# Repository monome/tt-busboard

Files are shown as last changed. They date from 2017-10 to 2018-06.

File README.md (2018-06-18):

# teletype busboard

provides 12 ii headers and additional pull-up to support larger ii networks.

## bom

see http://digikey.com

* (1) header, female, 2x3 [S7071-ND](https://www.digikey.com/products/en?keywords=S7071-ND)
* (12) header, male, 2x3 [609-3218-ND](https://www.digikey.com/products/en?keywords=609-3218-ND)
* (1) 3v3 reg [AZ1117CH-3.3TRG1DICT-ND](https://www.digikey.com/products/en?keywords=Z1117CH-3.3TRG1DICT-ND)
* (1) header, female, 2x5 [S6105-ND](https://www.digikey.com/products/en?keywords=S6105-ND)
* (2) resistor 1206 2.2k [P2.20KFCT-ND](https://www.digikey.com/products/en?keywords=P2.20KFCT-ND)
* (1) header, male, shrouded, 2x5 [ED1543-ND](https://www.digikey.com/products/en?keywords=ED1543-ND)

pcb via oshpark: https://oshpark.com/shared_projects/kg4mZSCg 

## guide

* full kit contents:

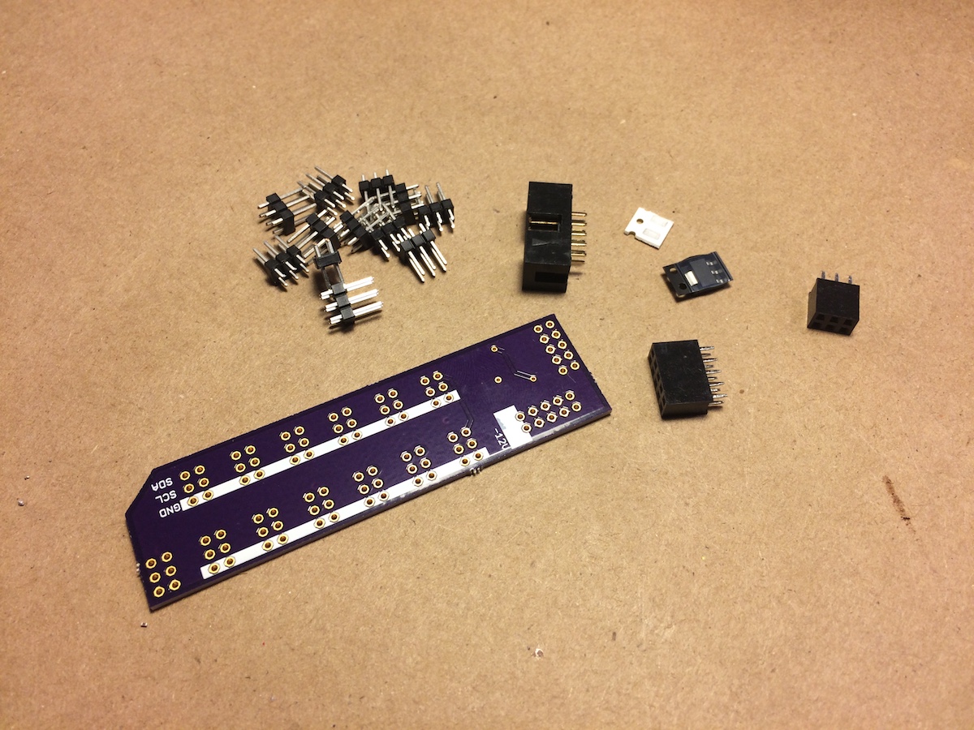
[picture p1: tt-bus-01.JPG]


* solder the SMD pads first, one for each part. use tweezers to place the part while heating the soldered pad with the iron. pull the iron away while holding the part, let the solder cool.

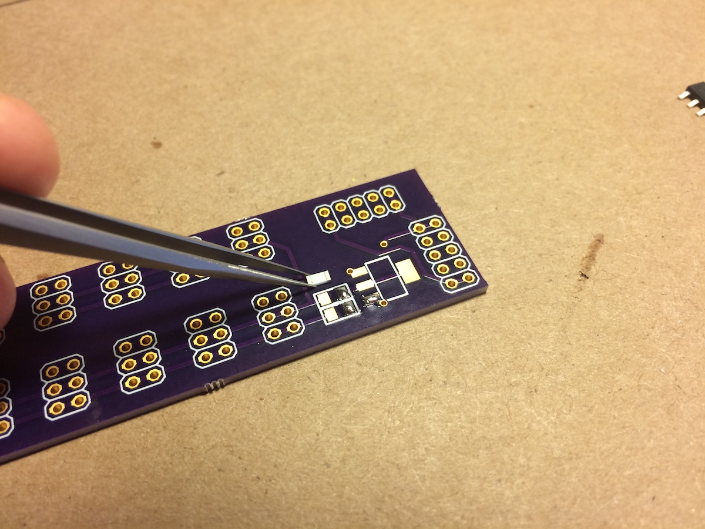
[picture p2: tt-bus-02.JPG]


* then solder the other remaining legs of the parts:

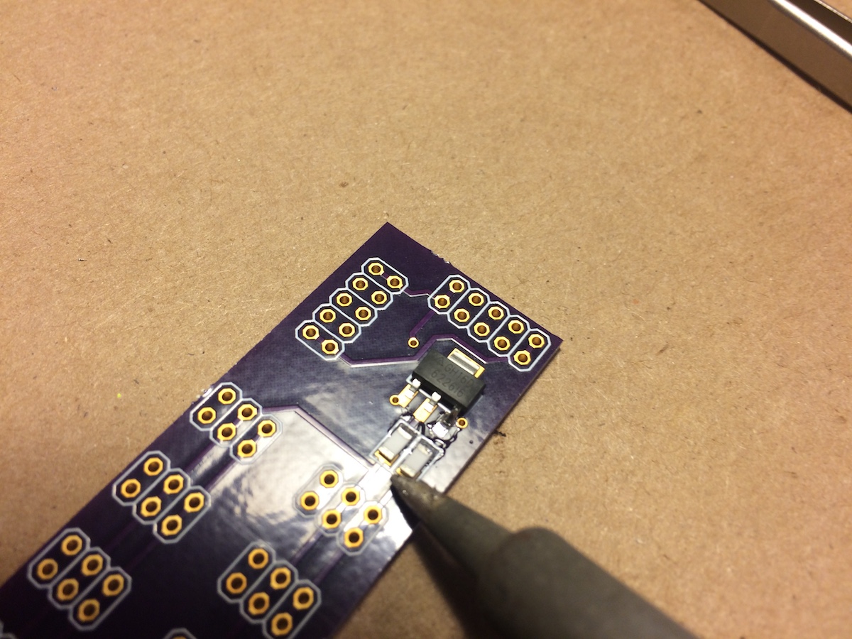
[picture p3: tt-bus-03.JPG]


* should look more or less like this:

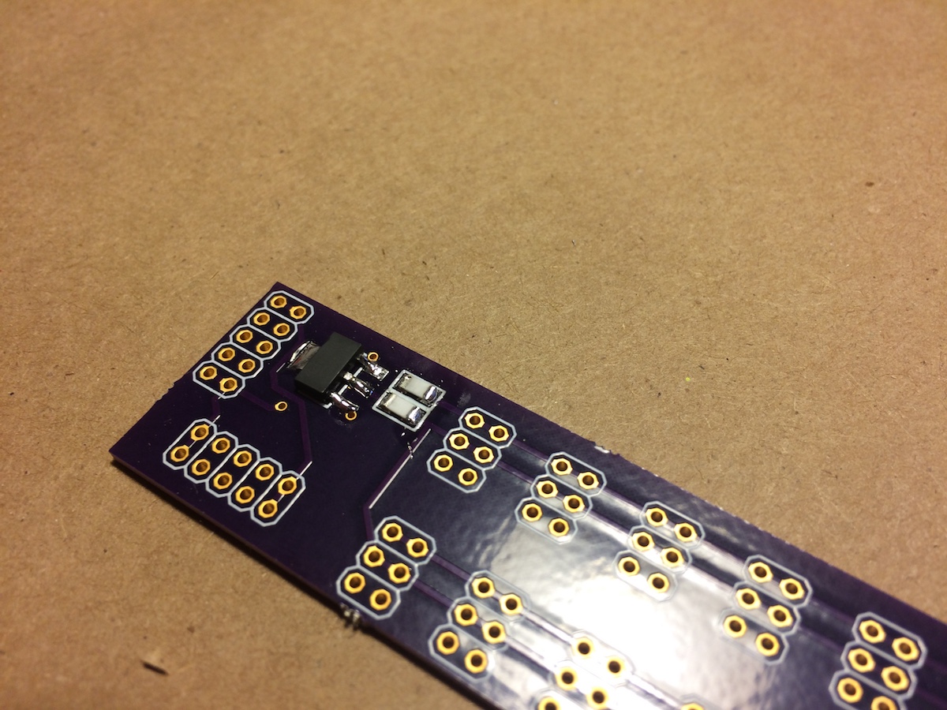
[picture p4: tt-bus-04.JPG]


* insert the 12 headers as shown and then solder the other side. may require a trick to flip it without having them fall out-- try a bit of cardboard to hold it all together while flipping:

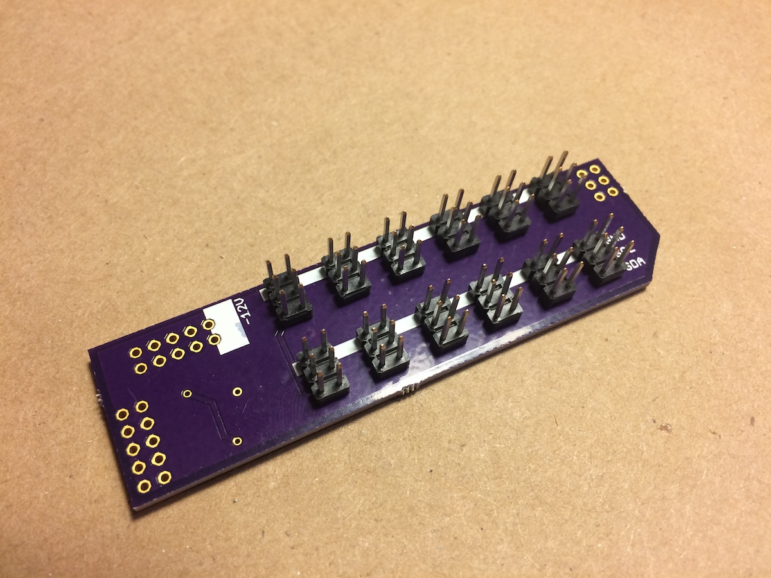
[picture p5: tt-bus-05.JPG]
 

* insert female headers as shown then solder:

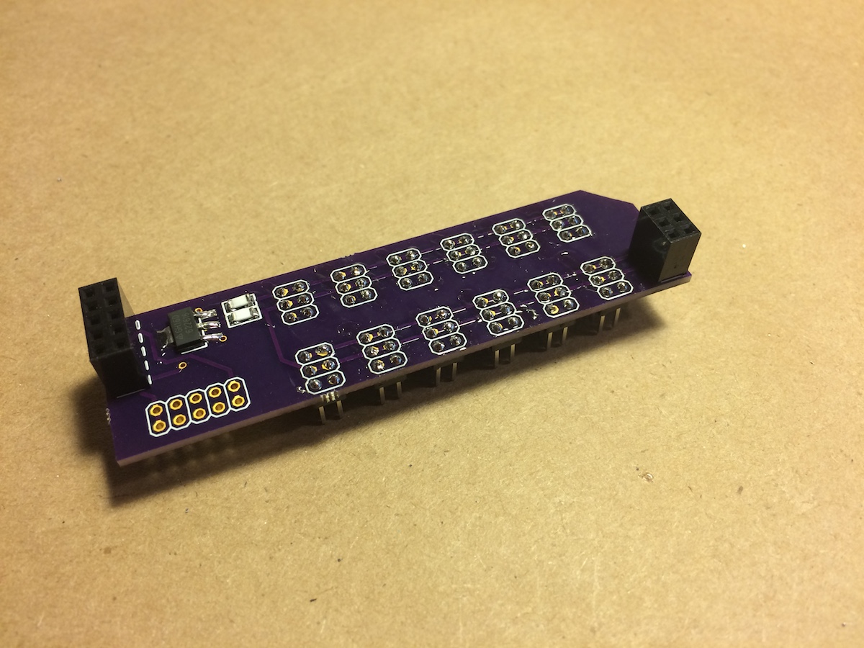
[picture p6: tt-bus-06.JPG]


* insert the power header and solder. *IMPORTANT* make sure the key cutout is towards the outside of the board:

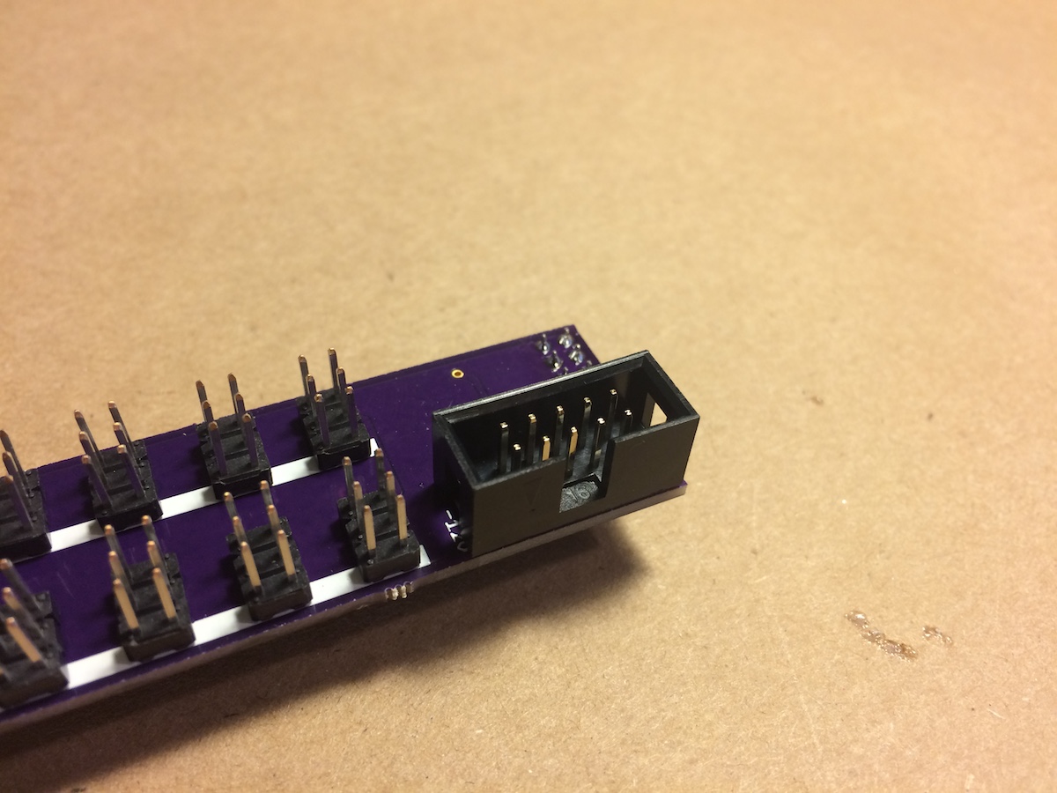
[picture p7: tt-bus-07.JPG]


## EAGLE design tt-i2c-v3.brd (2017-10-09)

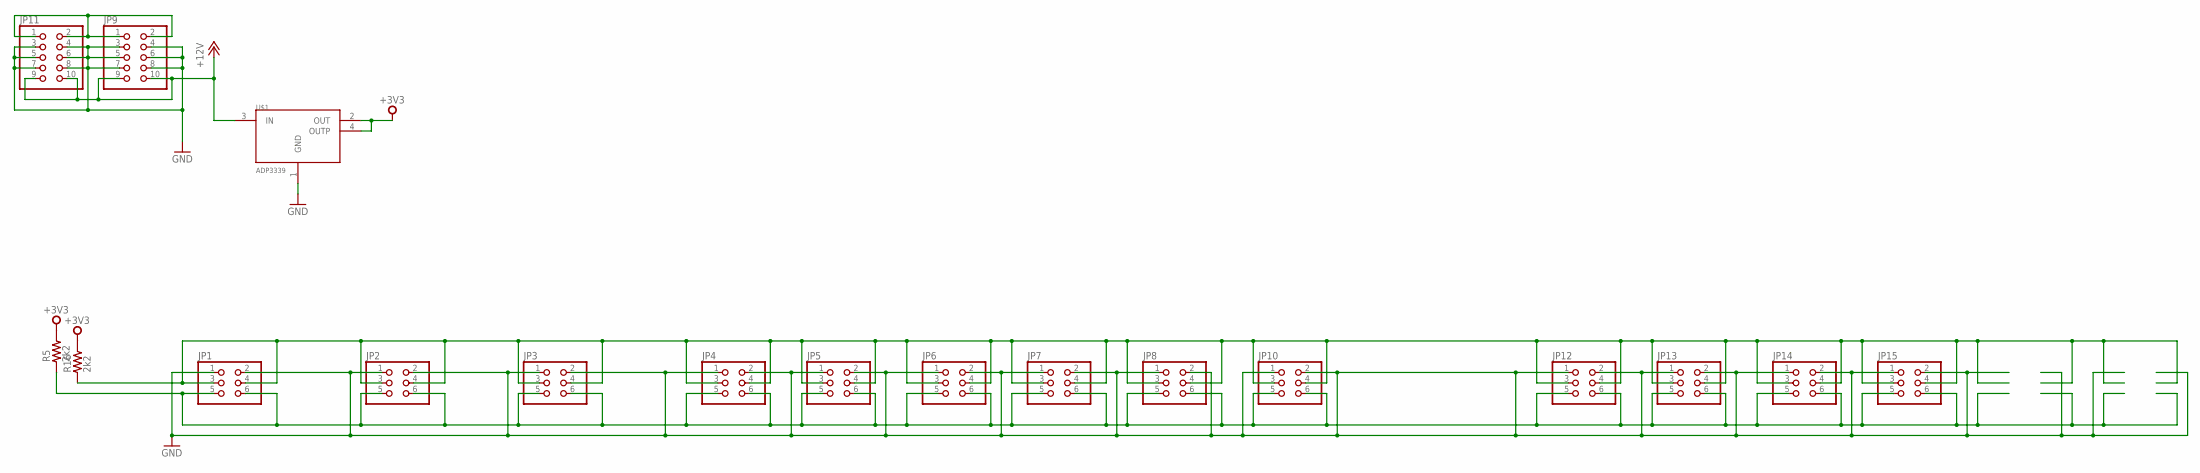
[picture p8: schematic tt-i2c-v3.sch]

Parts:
JP1, JP2, JP3, JP4, JP5, JP6, JP7, JP8, JP10, JP12, JP13, JP14, JP15: PINHD-2X3; 2X03
JP9, JP11: PINHD-2X5; 2X05
R5, R16: 2k2; R1206
U$1: ADP3339; SOT223

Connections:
+3V3: R5.2, R16.2, U$1.2 (OUT), U$1.4 (OUTP)
+12V: JP9.9, JP9.10, JP11.9, JP11.10, U$1.3 (IN)
GND: JP1.1, JP1.2, JP2.1, JP2.2, JP3.1, JP3.2, JP4.1, JP4.2, JP5.1, JP5.2, JP6.1, JP6.2, JP7.1, JP7.2, JP8.1, JP8.2, JP9.3, JP9.4, JP9.5, JP9.6, JP9.7, JP9.8, JP10.1, JP10.2, JP11.3, JP11.4, JP11.5, JP11.6, JP11.7, JP11.8, JP12.1, JP12.2, JP13.1, JP13.2, JP14.1, JP14.2, JP15.1, JP15.2, U$1.1 (GND)
unnamed: JP1.3, JP1.4, JP2.3, JP2.4, JP3.3, JP3.4, JP4.3, JP4.4, JP5.3, JP5.4, JP6.3, JP6.4, JP7.3, JP7.4, JP8.3, JP8.4, JP10.3, JP10.4, JP12.3, JP12.4, JP13.3, JP13.4, JP14.3, JP14.4, JP15.3, JP15.4, R16.1
unnamed: JP1.5, JP1.6, JP2.5, JP2.6, JP3.5, JP3.6, JP4.5, JP4.6, JP5.5, JP5.6, JP6.5, JP6.6, JP7.5, JP7.6, JP8.5, JP8.6, JP10.5, JP10.6, JP12.5, JP12.6, JP13.5, JP13.6, JP14.5, JP14.6, JP15.5, JP15.6, R5.1
unnamed: JP9.1, JP9.2, JP11.1, JP11.2

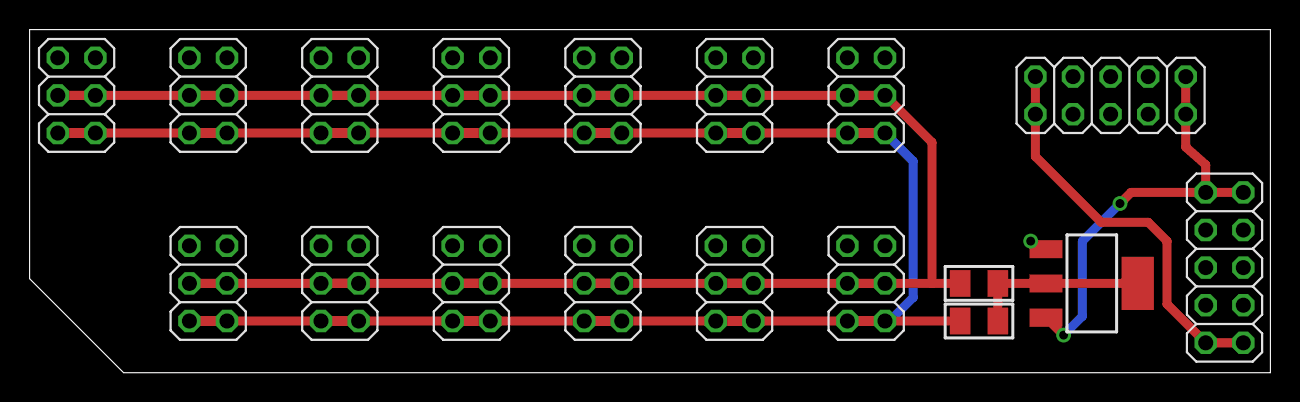
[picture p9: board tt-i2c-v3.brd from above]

Board: 2 copper layers, 83.8 x 23.2 mm, 18 parts (0 on the bottom side), 6 nets.
